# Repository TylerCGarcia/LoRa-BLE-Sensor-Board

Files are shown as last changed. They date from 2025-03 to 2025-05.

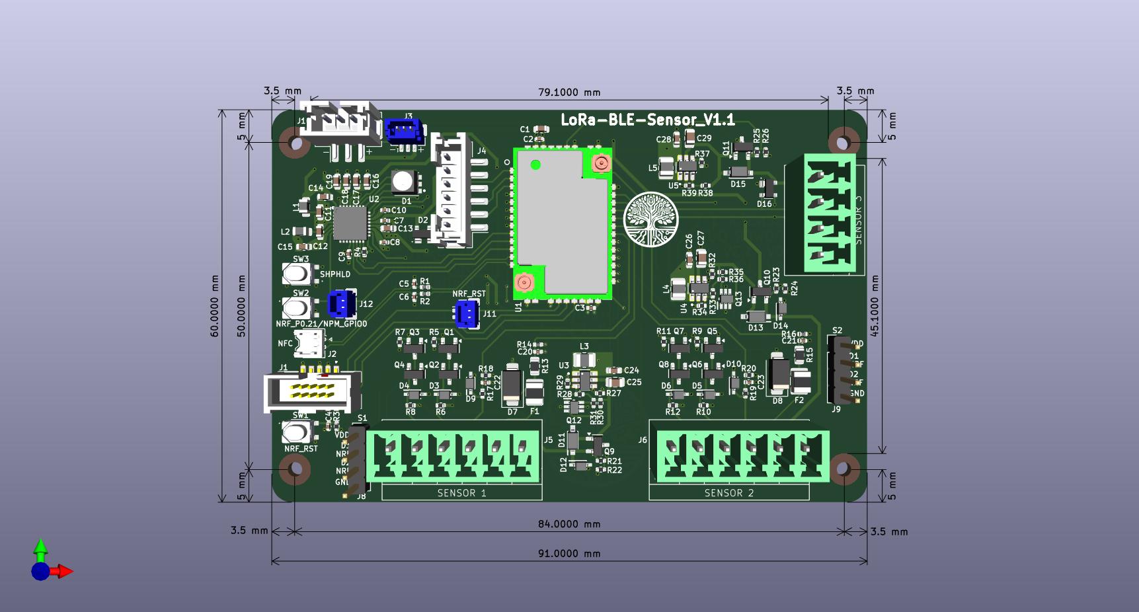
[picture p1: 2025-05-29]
docs/LoRa-BLE-Sensor_V1.1/LoRa-BLE-Sensor_V1.1.jpg

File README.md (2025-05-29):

# LoRa_BLE_Sensor Board
CAD: KiCad 9.0
# Overview
A RAK4630 based sensor board that uses BLE and LoRaWAN. This board is configured to use three industrial sensors simultaneously. 

Sensor 1 and Sensor 2 are designed so the sensor can be powered with 3.3V, 5V, 12V or 24V that are switched between through firmware. Sensor 3 has the options for 3.3V or 5V. It is designed for each sensor to have its own unique 
power supply, independent of the other sensor. Sensor 1 and Sensor 2 are designed for work with either digital or analog sensors. Sensor 3 is deisned for digital sensors with 3.3V logic level or to control up to two relays.

# Schematic Breakdown
**RAK4630** 
 - A combination module of an nRF52840 and SX1262
   * The nRF52840 has a cortex M4 and uses BLE
   * The SX1262 is a SPI controlled LoRa chip
 - There is an SWD connector for programming
 - There are two buttons
   * SW1 is connected to the reset pin on the nRF52840
   * SW2 is connected to P0.09

**NPM1300** 
 - Power management for the board
   * Programmable over I2C with the RAK4630
 - Used to charge the battery and works as a fuel guage
 - Contains two buck converters
   * Buck 1 is used for Sensor 3 3.3V output
   * Buck 2 is used at 3.3V to supply Vdd for the entire board
 - Contains 2 LDOs
   * Used if either Sensor 1 or Sensor 2 are set to 3.3V
 - Switch SW3
   * Used to change power modes on npm1300 or to do a power cycle of the board
 - RGB LED
   * Used for charging/error status of the npm1300 and as an led controlled by RAK4630

**Boost 1** 
 - TLV61046ADBVR Boost Converter
   * Up to 28V output with load disconnect
   * Output is determined by resistors in feedback
 - NMOS mosfets
   * Allow for feedback reistances to be changes to adjust output
   * BOOST1_FB_CTRL1 set to 0, BOOST1_FB_CTRL2 set to 0 --> 24V
   * BOOST1_FB_CTRL1 set to 1, BOOST1_FB_CTRL2 set to 0 --> 12V
   * BOOST1_FB_CTRL1 set to 0, BOOST1_FB_CTRL2 set to 1 --> 6V
   * BOOST1_FB_CTRL1 set to 1, BOOST1_FB_CTRL2 set to 1 --> 5V

**Boost 2** 
 - TLV61046ADBVR Boost Converter
   * Up to 28V output with load disconnect
   * Output is determined by resistors in feedback
 - NMOS mosfets
   * Allow for feedback reistances to be changes to adjust output
   * BOOST2_FB_CTRL1 set to 0, BOOST2_FB_CTRL2 set to 0 --> 24V
   * BOOST2_FB_CTRL1 set to 1, BOOST2_FB_CTRL2 set to 0 --> 12V
   * BOOST2_FB_CTRL1 set to 0, BOOST2_FB_CTRL2 set to 1 --> 6V
   * BOOST2_FB_CTRL1 set to 1, BOOST2_FB_CTRL2 set to 1 --> 5V

**Boost 3** 
 - TLV61046ADBVR Boost Converter
   * Up to 28V output with load disconnect
   * Output is determined by resistors in feedback
 - This boost has one configuration which is 5V

**Sensor 3 ESD**
 - ESD protection for Sensor 3 power and digital lines
  * ESD is for 5V for power and 3.3V for input lines

**Power Switches** 
 - Connects boost and ldo/buck outputs so only 1 is used by the sensor
   * Boost outputs have priority if both are enabled
 - ESD protection for sensor power
   * Designed for 24V for Sensor 1 and Sensor 2
   
**Digital Inputs** 
 - MOSFET based level shifters
   * Allows sensor digital logic to be translated from sensor power to Vdd
 - ESD protection for digital inputs
   * Designed for 24V for Sensor 1 and Sensor 2

**Analog Inputs** 
 - 5 inputs meant for external sensors
   * 2 designed for 4-20mA current sensors
   * 2 designed to read voltages up to 28V
   * 3 designed for feedback to the voltage of the sensor power

**USB** 
 - 6 pin jst PH connector to use with external USB-C connector
 - ESD protection for data lines and USB power

**Interface** 
 - Three screw terminal connectors for the sensors
   * Designed for pluggaple screw terminals
 
**Debug**
 - Two JST SH connectors for interfacing with Button 1 and nRF Reset
 - Two 2.54mm pin header for debugging Sensor 1 and Sensor 2

# Power Analysis

# Bugs/To-Do
- Add fuses to sensor power outputs

# Revision History
Current Version: **V1.1**

Version Breakdown: `[Major Chanegs]`.`[Minor Changes]`

### V1.1
- Changed level shifters for sensor to have isolation from output
- Removed 18650 battery connectors and NTC
  * Replaced with 3 pin JST PH and JST SH for external battery
- Removed on board relay
- Added Sensor 3 connectors
 * Can be configured for digital sensors with 3.3V or 5V output
 * Output is either 5V from boost converter or Buck 1 of npm1300
 * This connector can be used for an external relay
- Added 2 pin JST SH connectors to have Button 1 and nRF Reset pins be external if desired
- Added connector for NFC antenna
- Changed mounting holes from M3 to M2

### V1.0
- Initial Design of Board

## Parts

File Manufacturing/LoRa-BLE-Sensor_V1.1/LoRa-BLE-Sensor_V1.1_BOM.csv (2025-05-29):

Item # | Ref Des | Qty | Manufacturer | Mfg Part # | Description/Value | Package | Type | Price per Part for 10 | Price per Board | Price per Part for 100 | Price per Board | Distributor
1 | U1 | 1 | RAK Wireless | RAK4630 | BLE/LoRa Wireless Module nRF52840 and SX1262 | 24-TFQFN | SMD | $15.00 | $15.00 | $15.00 | $15.00 | RAK
2 | U2 | 1 | Nordic Semiconductor | nPM1300-QEAA-R | Battery Management POWER MANAGEMENT IC | GFN32 | SMD | $1.68 | $1.68 | $1.50 | $1.50 | Digikey
3 | U3, U4, U5 | 3 | Texas Instruments | TLV61046ADBVR | BOOST CONVERTER 28V OUTPUT ADJUSTABLE | SOT-23-6 | SMD | $0.79 | $2.37 | $0.71 | $2.14 | Mouser
4 | Q1, Q2, Q3, Q4, Q5, Q6, Q7, Q8 | 8 | Diodes Incorporated | DMN67D7L-7 | N-CHANNEL 1 CHANNEL 40VGS 60VDS 800mVGSth 1.5Ohms | SOT-23-3 | SMD | $0.13 | $1.06 | $0.08 | $0.66 | Mouser
5 | Q9, Q10, Q11 | 3 | Vishay | SQ2389ES-T1_GE3 | P-CHANNEL 1 CHANNEL 20VGS 40VDS 1.5VGSth 94mOhms | SOT-23-3 | SMD | $0.50 | $1.50 | $0.38 | $1.15 | Mouser
6 | Q12, Q13 | 2 | Diodes Incorporated | DMN62D0UDW-7 | N-CHANNEL 2 CHANNEL 20VGS 60VDS 500mVGSth 2Ohms | SOT-363-6 | SMD | $0.13 | $0.27 | $0.09 | $0.18 | Mouser
7 | D1 | 1 | Broadcom | ASMB-TTF0-0A20B | RGB LED 20mA 2.1V, 2.9V, 2.9V | PLCC-6 | SMD | $0.31 | $0.31 | $0.18 | $0.18 | Mouser
8 | D2, D16 | 2 | Nexperia | PRTR5V0U2X,215 | ESD Bidirectional DIODE 2 CHANNEL 5V Working 6V BREAKDOWN 1pF | SOT-143B-4 | SMD | $0.33 | $0.66 | $0.23 | $0.46 | Mouser
9 | D3, D4, D5, D6, D9, D10, D12, D14 | 8 | YAGEO | UDD32C24L01 | ESD Bidirectional Diode 24V Working 56V Clamp 26.7V Breakdown 0.8pF | SOD-323 | SMD | $0.18 | $1.46 | $0.09 | $0.71 | Mouser
10 | D7, D8 | 2 | Littlefuse | SMAJ10CA | ESD Bidirectional Diode 17V Clamp 11.1V Breakdown 23.5A | DO-214AC | SMD | $0.26 | $0.52 | $0.21 | $0.42 | Mouser
11 | D11, D13, D15 | 3 | Vishay | BAT54W-HG3-08 | Schottky Diode 240mV 200mA | SOD-123-2 | SMD | $0.18 | $0.55 | $0.12 | $0.35 | Mouser
12 | L1, L2 | 2 | Murata | LQM21PH2R2MGCD | IND SHIELDED 2.2uH 800mA DC 290mOhms | 0805 | SMD | $0.19 | $0.38 | $0.15 | $0.30 | Mouser
13 | L3, L4, L5 | 3 | Murata | 1239AS-H-100M=P2 | IND SHIELDED 10UH 850mA DC 460mOhms | 1008 | SMD | $0.21 | $0.63 | $0.16 | $0.49 | Mouser
14 | F1, F2 | 2 | Bourns | MF-USMF005-2 | PTC Resettable Fuse 30V 150mA Trip 2.8Ohm Initial 50 Ohm Post Trip 50mA Hold | 1210 | SMD | $0.30 | $0.61 | $0.23 | $0.47 | Mouser
15 | C1, C11, C12, C13, C14, C15, C16, C17, C18, C19, C24, C26, C28 | 13 | Murata | GRM188Z71A106MA73J | CAP CER 10UF 10VDC 20% X7R | 0603 | SMD | $0.21 | $2.68 | $0.13 | $1.69 | Mouser
16 | C25, C27, C29 | 3 | Murata | GRM21BR61H106ME43L | CAP CER 10UF 50VDC 20% X5R | 0805 | SMD | $0.22 | $0.66 | $0.13 | $0.38 | Mouser
17 | C2, C3, C4, C9 | 4 | Murata | GRM155R71C104KA88J | CAP CER 100NF 16VDC 10% X7R | 0402 | SMD | $0.01 | $0.02 | $0.00 | $0.02 | Mouser
18 | C5, C6 | 2 |  |  | DNP | 0402 | DNP
19 | C7, C10 | 2 | Murata | GRM155Z71A105KE01D | CAP CER 1UF 10VDC 10% X7R | 0402 | SMD | $0.02 | $0.04 | $0.02 | $0.03 | Mouser
20 | C8 | 1 | Murata | GRM155Z71A225KE01D | CAP CER 2.2UF 10VDC 10% X7R | 0402 | SMD | $0.11 | $0.11 | $0.06 | $0.06 | Mouser
21 | C20, C21, C22, C23 | 4 | Murata | GRM1555C1H471JA01D | CAP CER 470pF 50V 5% C0G | 0402 | SMD | $0.03 | $0.12 | $0.02 | $0.07 | Mouser
22 | R1, R2 | 2 | Panasonic | ERJ-2GE0R00X | RES 0 OHM 1/10W 5% 0PPM/C | 0402 | SMD | $0.01 | $0.02 | $0.01 | $0.02 | Mouser
23 | R3, R5, R6, R7, R8, R9, R10, R11, R12, R27, R32, R37 | 12 | Panasonic | ERJ-2RKF1002X | RES 10K OHM 1/10W 1% 50V 100PPM/C | 0402 | SMD | $0.02 | $0.28 | $0.01 | $0.16 | Mouser
24 | R4 | 1 | Panasonic | ERJ-2RKF3003X | RES 300K OHM 1/10W 1% 50V 100PPM/C | 0402 | SMD | $0.02 | $0.02 | $0.01 | $0.01 | Mouser
25 | R13, R15 | 2 | Panasonic | ERJ-UP6F1800V | RES 180 OHM 1/2W 1% 400V 100PPM/C | 0805 | SMD | $0.09 | $0.17 | $0.06 | $0.12 | Mouser
26 | R14, R16 | 2 | Vishay | TNPW040250R0DEED | RES 50 OHM 130mW 0.5% 75V 25PPM/C | 0402 | SMD | $0.14 | $0.28 | $0.10 | $0.20 | Mouser
27 | R17, R19 | 2 | Panasonic | ERA-2AEB104X | RES 100K OHM 1/16W 0.1% 50V 25PPM/C | 0402 | SMD | $0.09 | $0.17 | $0.08 | $0.15 | Mouser
28 | R18, R20 | 2 | Panasonic | ERA-2AEB133X | RES 13K OHM 1/16W 0.1% 50V 25PPM/C | 0402 | SMD | $0.09 | $0.17 | $0.08 | $0.15 | Mouser
29 | R21, R23, R25 | 3 | YAGEO | RE0402DRE071ML | RES 1M OHM 1/16W 0.5% 50V 50PPM/C | 0402 | SMD | $0.03 | $0.08 | $0.02 | $0.06 | Mouser
30 | R22, R24, R26 | 3 | KOA Speer | RN73R1ETTP1303B25 | RES 130KOHM 1/10W 0.1% 50V 25PPM/C | 0402 | SMD | $0.07 | $0.20 | $0.06 | $0.19 | Mouser
31 | R28, R33 | 2 | Vishay | CRCW04022M10FKED | RES 2.1M OHM 1/16W 1% 50V 100PPM/C | 0402 | SMD | $0.02 | $0.03 | $0.01 | $0.03 | Mouser
32 | R29, R34, R39 | 3 | Vishay | CRCW040271K5FKED | RES 71.5K OHM 1/16W 1% 50V 100PPM/C | 0402 | SMD | $0.02 | $0.06 | $0.02 | $0.05 | Mouser
33 | R30, R35 | 2 | Vishay | CRCW04021M96FKED | RES 1.96M OHM 1/16W 1% 50V 100PPM/C | 0402 | SMD | $0.02 | $0.03 | $0.01 | $0.03 | Mouser
34 | R31, R36 | 2 | Vishay | CRCW0402604KFKED | RES 604K OHM 1/16W 1% 50V 100PPM/C | 0402 | SMD | $0.02 | $0.03 | $0.01 | $0.03 | Mouser
35 | R38 | 1 | Vishay | CRCW0402383KFKED | RES 383K OHM 1/16W 1% 50V 100PPM/C | 0402 | SMD | $0.03 | $0.03 | $0.02 | $0.02 | Mouser
36 | SW1, SW2, SW3 | 3 | C&K | PTS815SJM250SMTR LFS | Tactile Switch 12VDC 50mA 4.2mm x 3.2mm x 1.55mm |  | SMD | $0.19 | $0.58 | $0.16 | $0.47 | Mouser
37 | J1 | 1 | ANY | SHF-105-01-L-D-SM-TR | 10 PIN SHROUDED 2x5 DIRECTIONAL 1.27mm PITCH |  | SMD | $0.16 | $0.16 | $0.16 | $0.16 | AliExpress
38 | J2 | 1 | JST | BM02B-ACHSS-GAN-ETF | 2-PIN JST ACH 1.2mm |  | SMD | $0.44 | $0.44 | $0.37 | $0.37 | LCSC
39 | J3 | 1 | JST | BM03B-SRSS-TB | 3-PIN JST SH HEADER VERTICAL 1mm PITCH |  | SMD | $0.21 | $0.21 | $0.16 | $0.16 | LCSC
40 | J4 | 1 | JST | B6B-PH-SM4-TB(LF)(SN) | 6-PIN JST PH HEADER VERTICAL 2mm PITCH |  | SMD | $0.32 | $0.32 | $0.25 | $0.25 | LCSC
41 | J5, J6 | 2 | Pheonix Contact | 1803468 | 6 Input Screw Terminal 3.81 mm Pitch Plug Connector |  | Thru-Hole | $0.60 | $1.20 | $0.32 | $0.64 | AliExpress
42 | J7 | 1 | Pheonix Contact | 1803442 | 4 Input Screw Terminal 3.81 mm Pitch Plug Connector |  | Thru-Hole | $0.50 | $0.50 | $0.50 | $0.50 | AliExpress
43 | J8, J9 | 2 | ANY |  | 1x4 Pin Header 2.54mm Pitch |  | Thru-Hole | $0.10 | $0.20 | $0.10 | $0.20 | AliExpress
44 | J10 | 1 | JST | B3B-PH-SM4-TB | 3-PIN JST PH HEADER VERTICAL 2mm PITCH |  | SMD | $0.21 | $0.21 | $0.17 | $0.17 | LCSC
45 | J11, J12 | 2 | JST | BM02B-SRSS-TB | 2-PIN JST SH HEADER VERTICAL 1mm PITCH |  | SMD | $0.14 | $0.28 | $0.11 | $0.22 | LCSC
 | Total Components | 124 |  |  |  |  |  | Total Price | $36.28 | Total Price | $30.59

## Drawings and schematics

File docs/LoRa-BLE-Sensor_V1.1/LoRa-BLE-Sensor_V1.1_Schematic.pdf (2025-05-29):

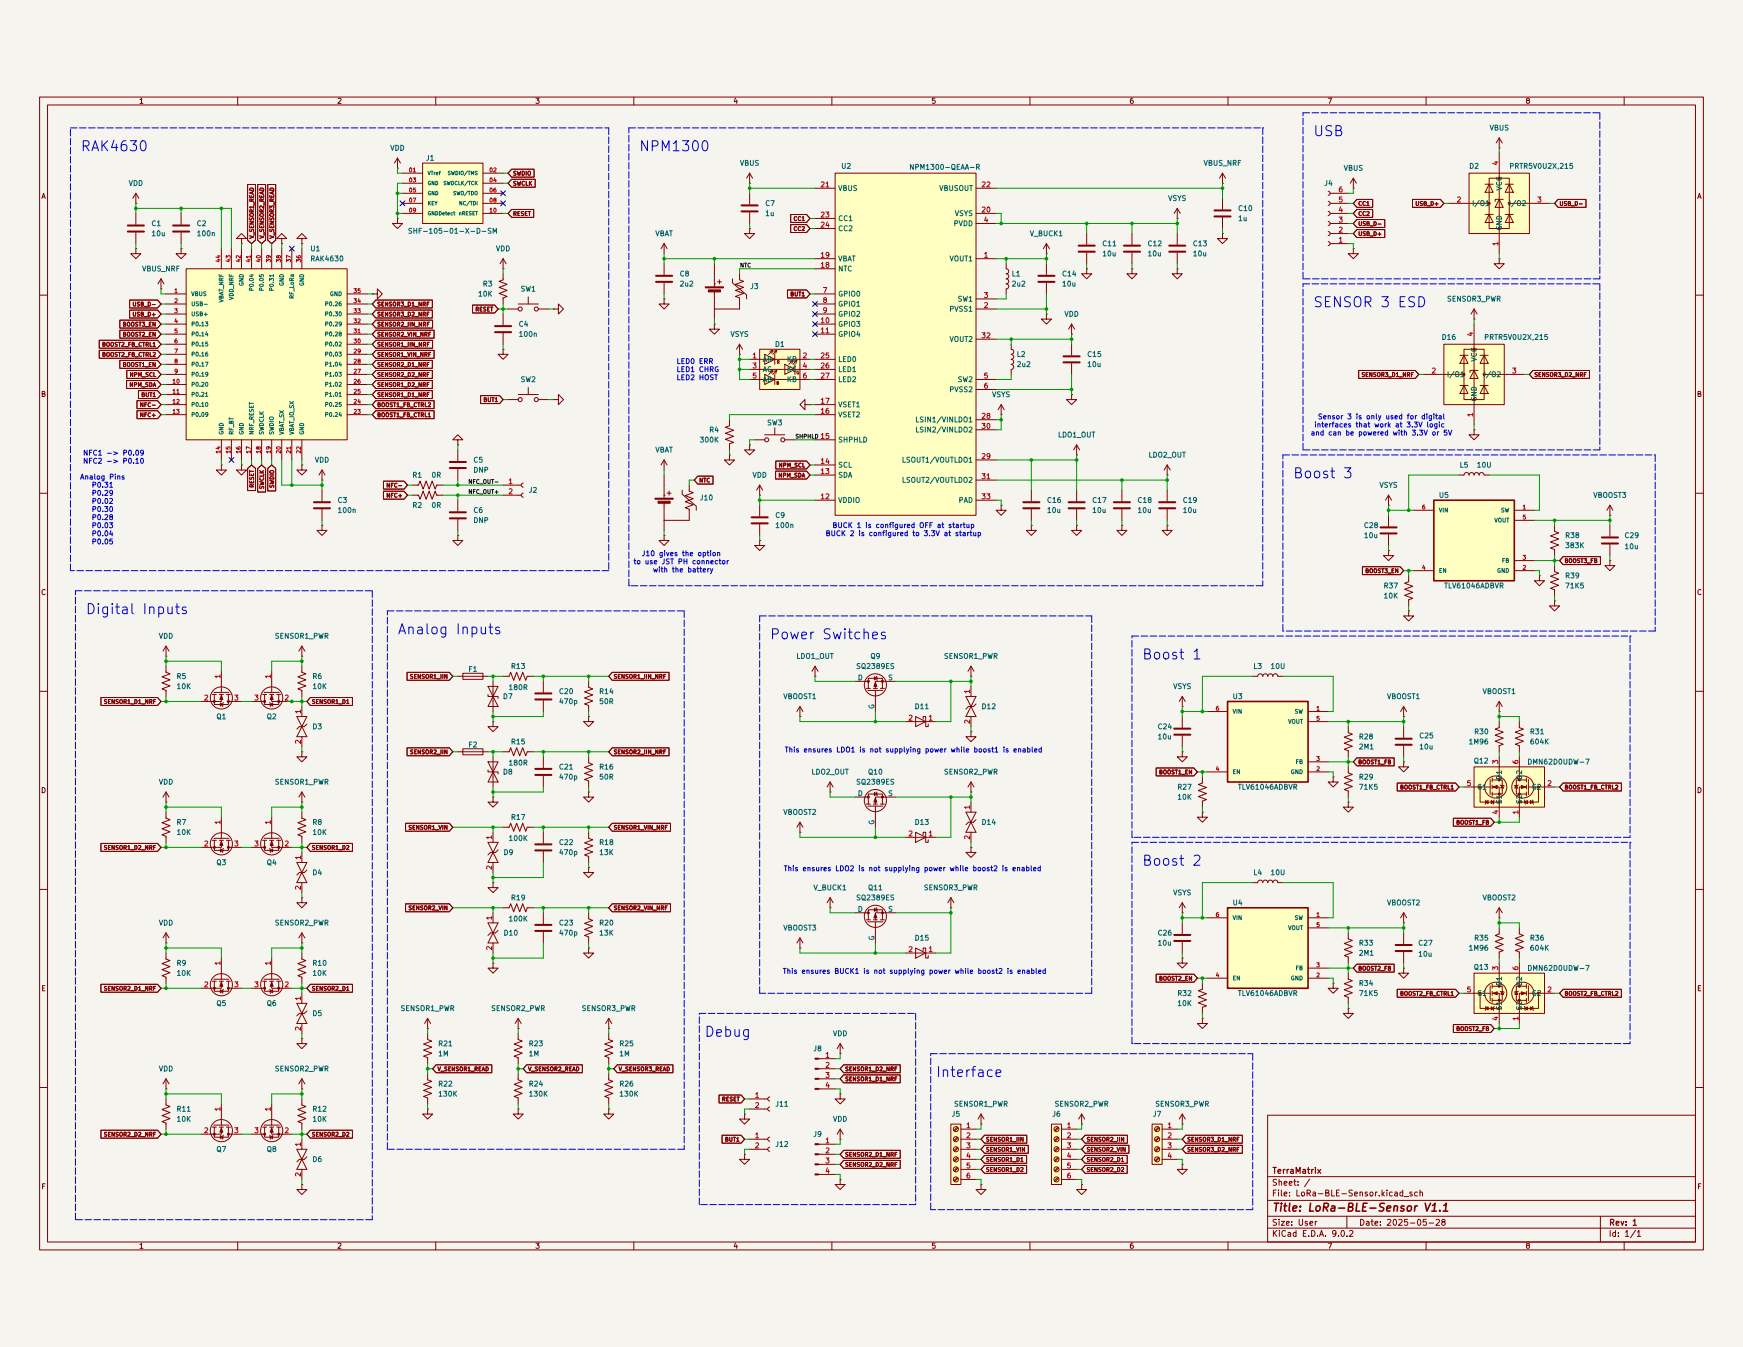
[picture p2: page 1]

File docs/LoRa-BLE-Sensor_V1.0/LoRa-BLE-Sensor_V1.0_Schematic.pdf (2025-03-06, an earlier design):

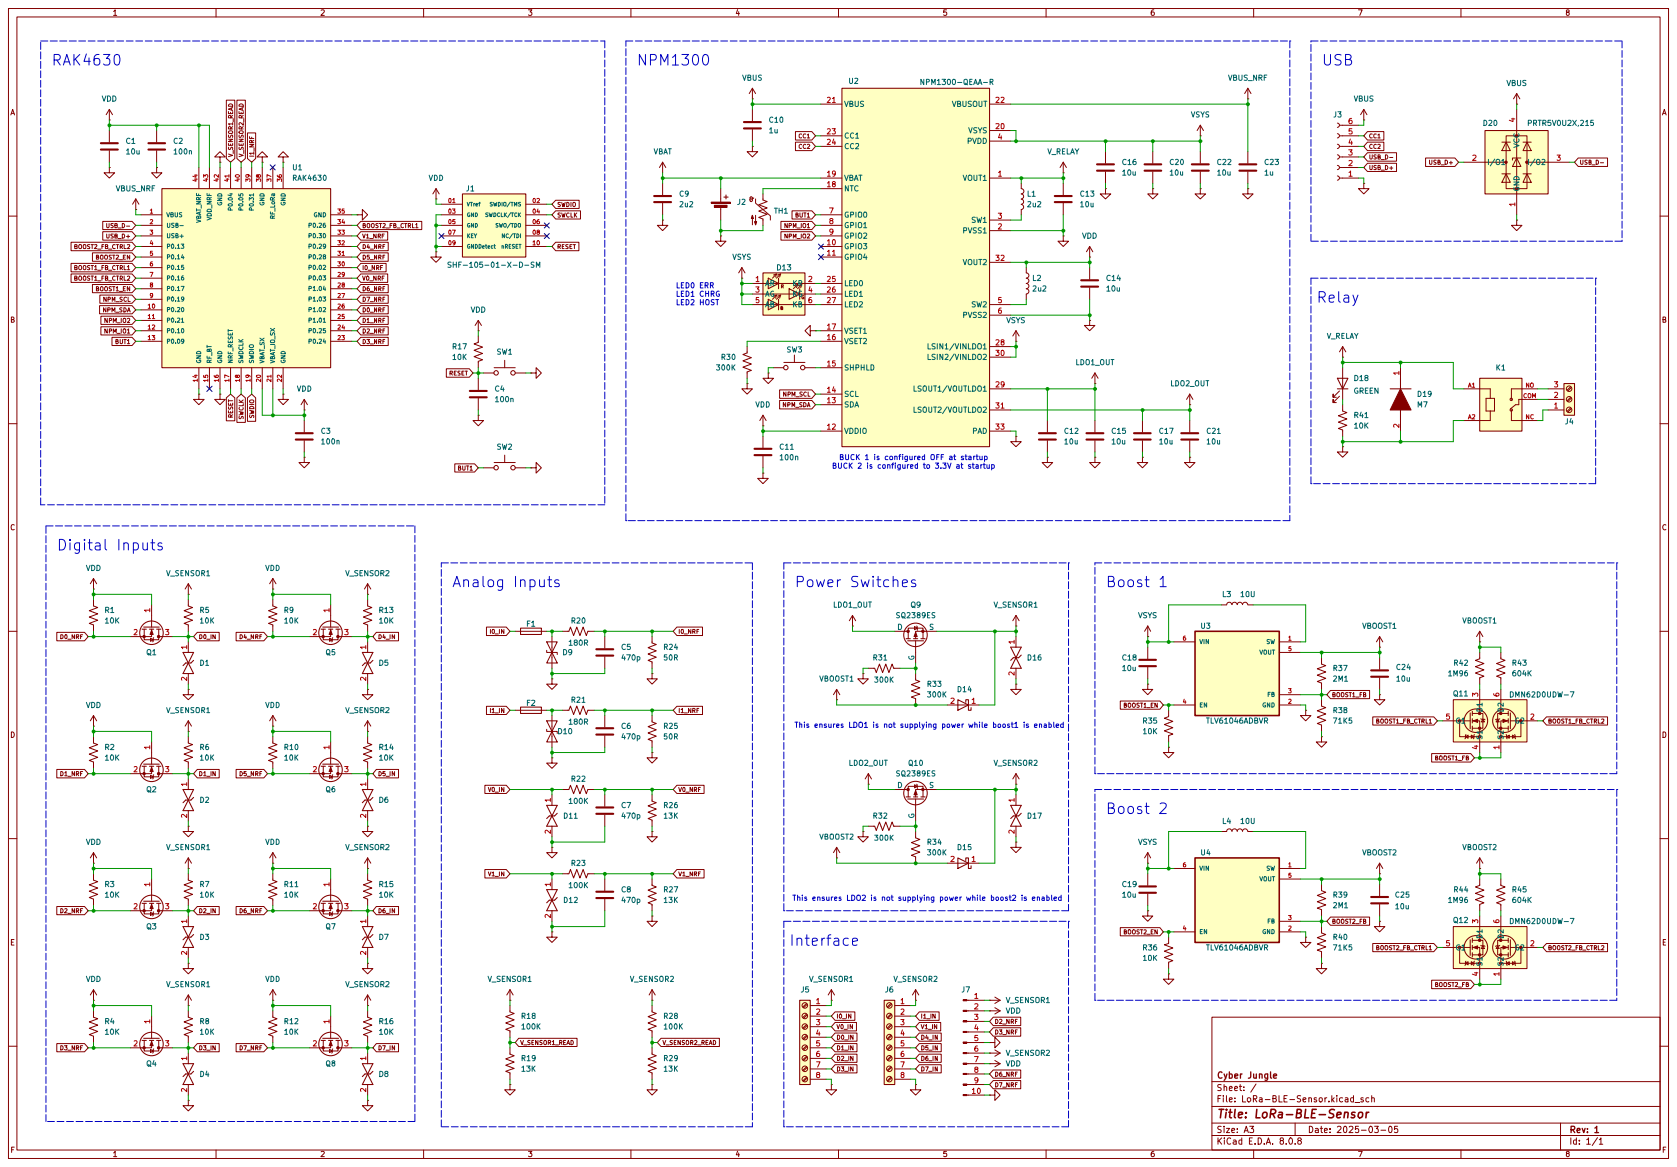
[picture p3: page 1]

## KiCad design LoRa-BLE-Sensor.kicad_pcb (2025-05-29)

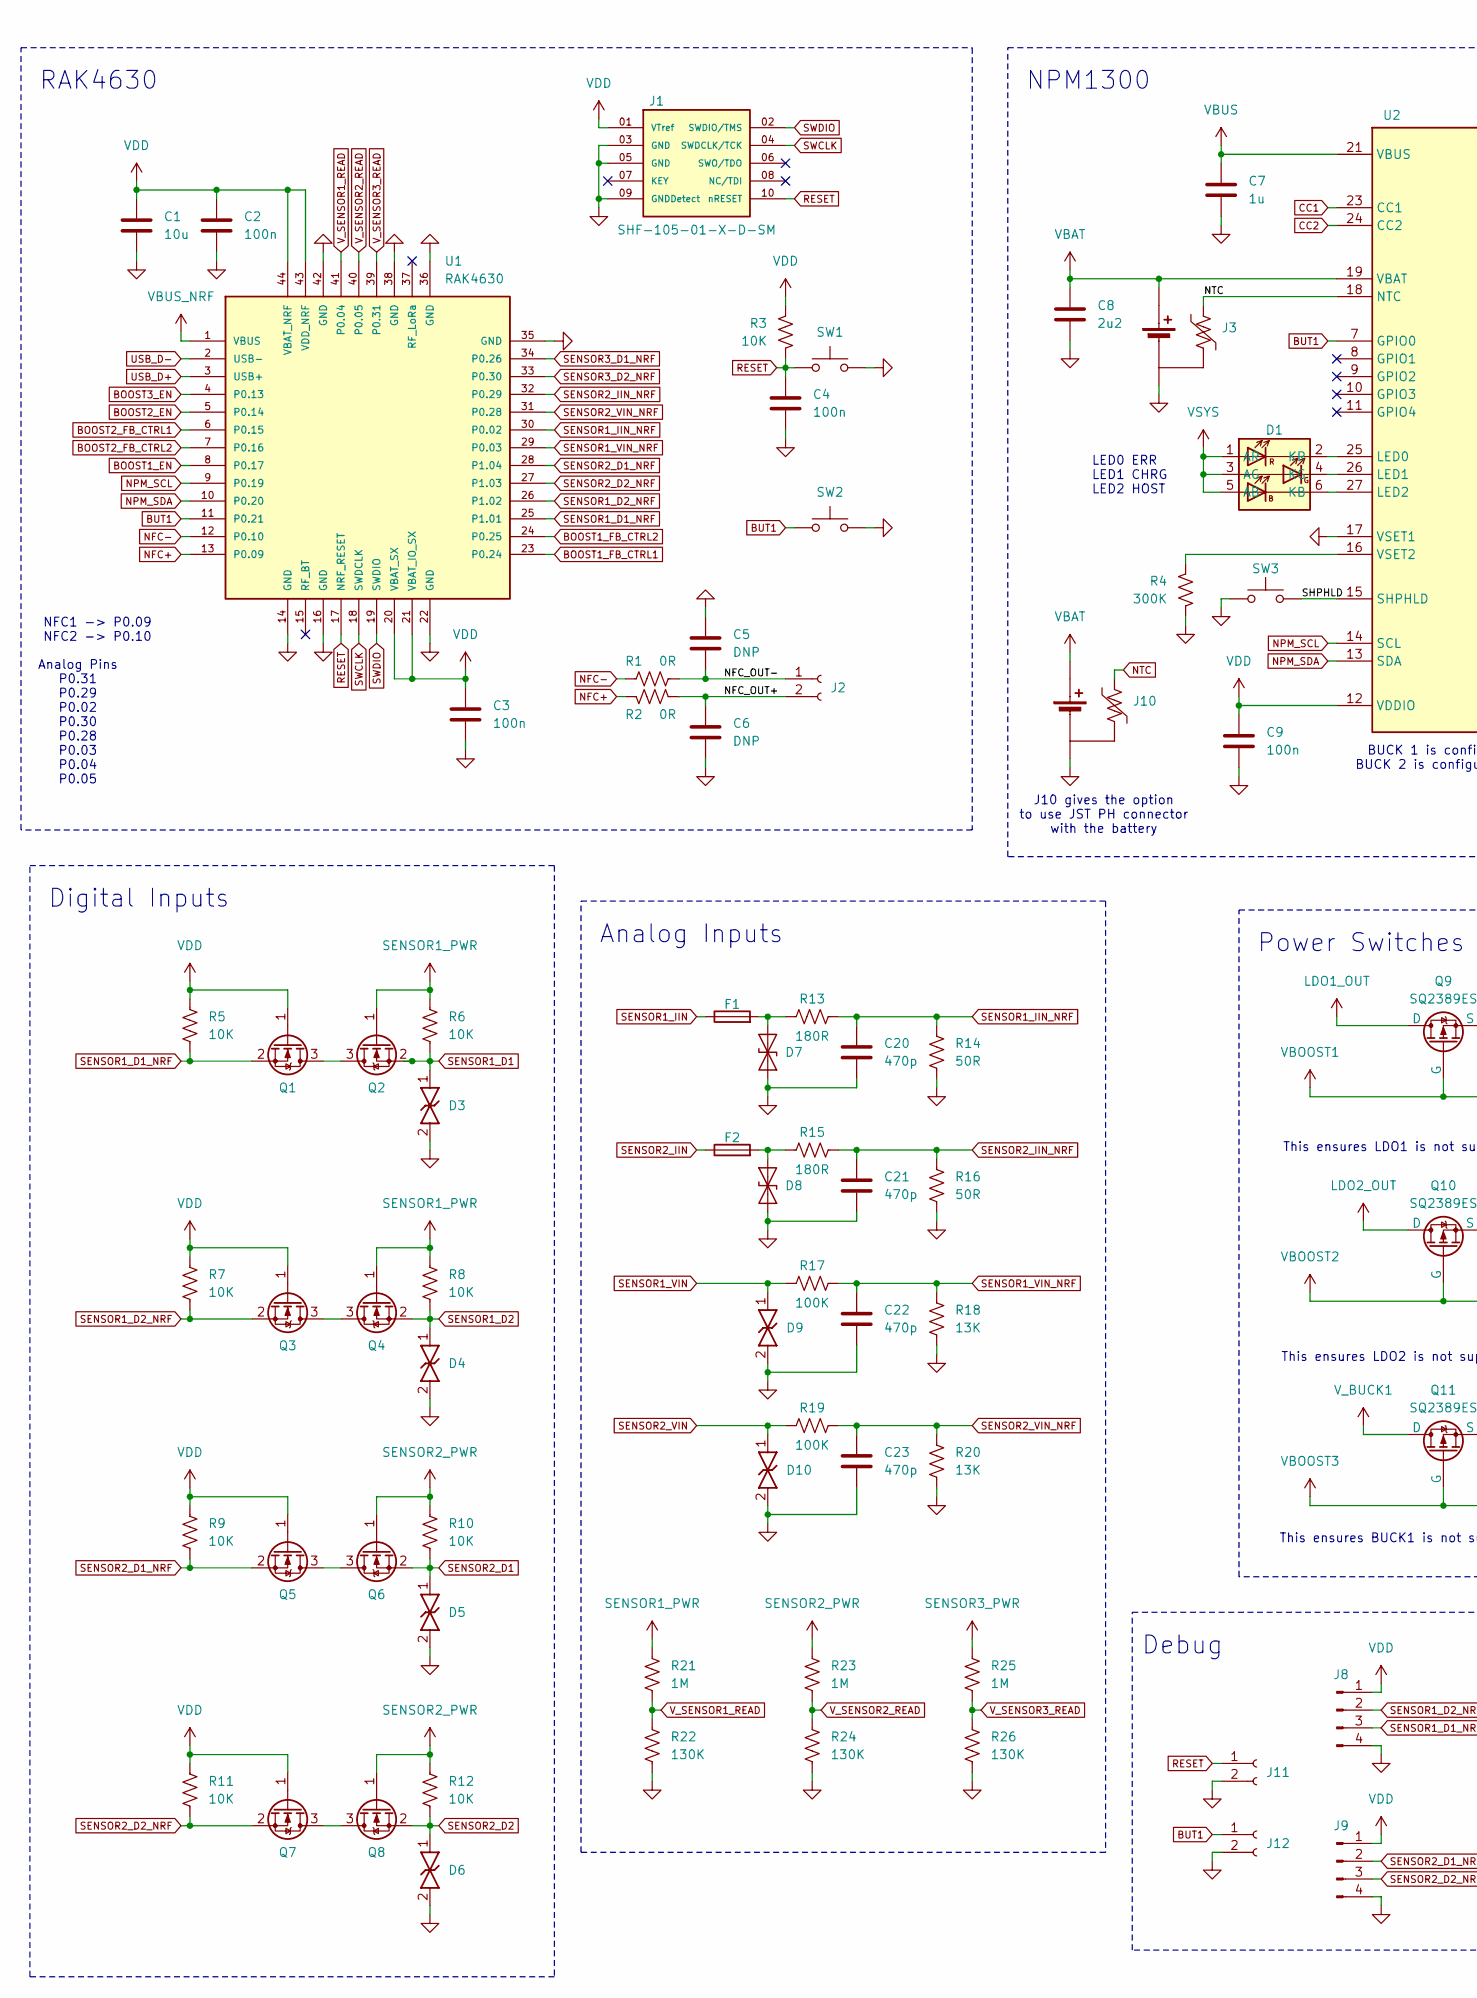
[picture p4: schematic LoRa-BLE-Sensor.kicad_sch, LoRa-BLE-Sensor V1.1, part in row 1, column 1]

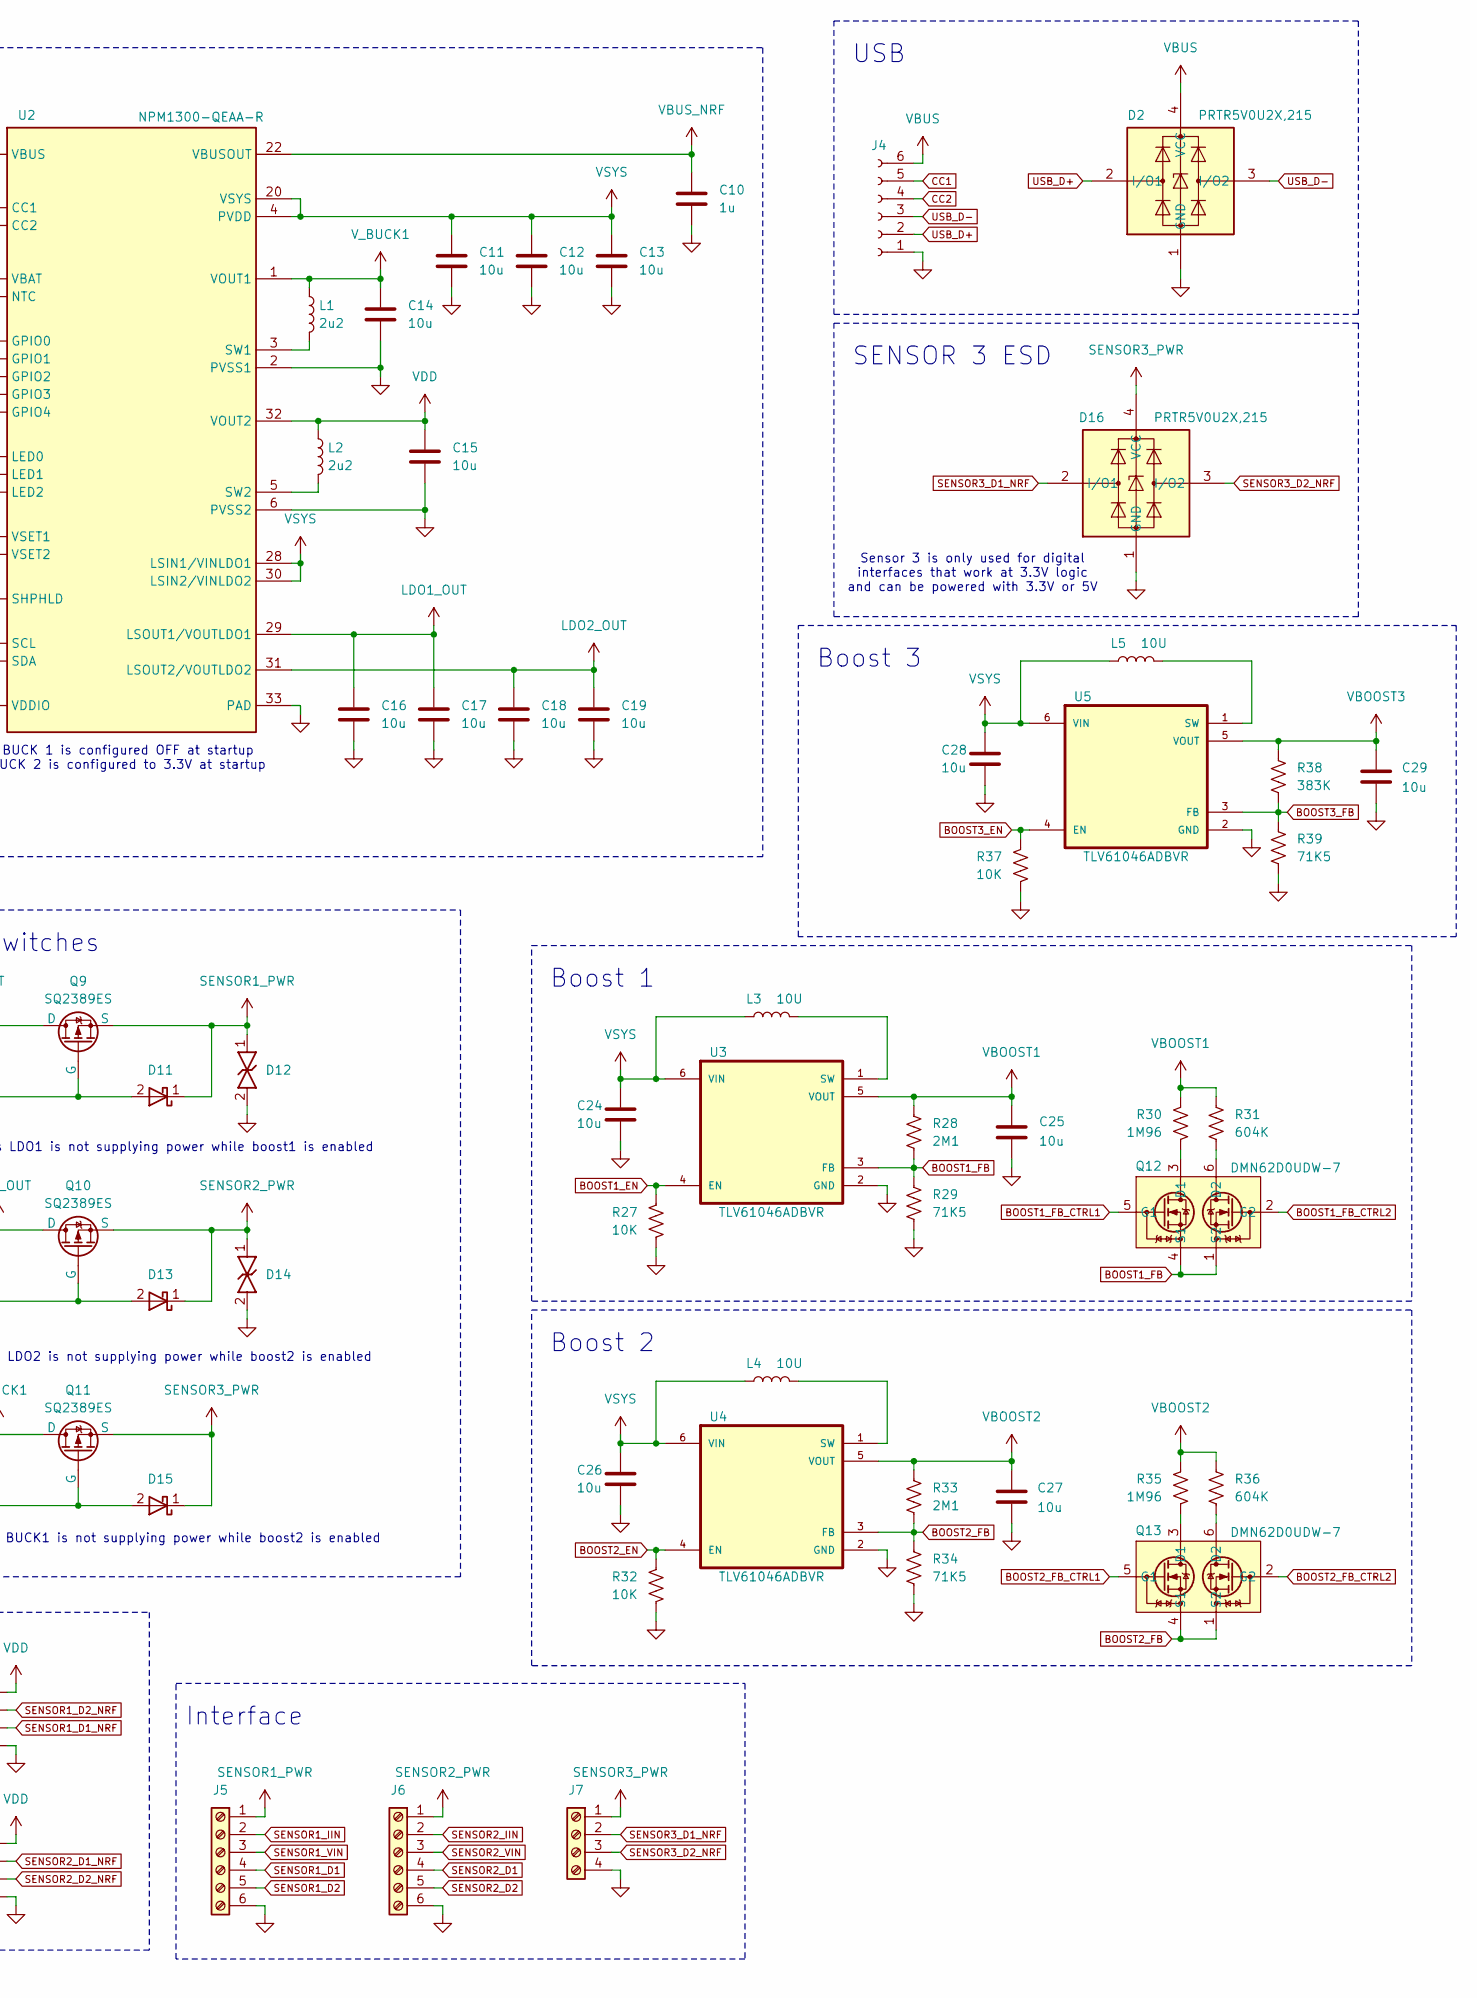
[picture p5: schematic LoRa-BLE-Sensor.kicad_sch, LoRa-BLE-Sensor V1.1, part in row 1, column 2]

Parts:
C1, C11, C12, C13, C14, C15, C16, C17, C18, C19, C24, C26, C28: 10u; C_0603_1608Metric
C2, C3, C4, C9: 100n; C_0402_1005Metric
C5, C6: DNP; C_0402_1005Metric
C7, C10: 1u; C_0402_1005Metric
C8: 2u2; C_0402_1005Metric
C20, C21, C22, C23: 470p; C_0402_1005Metric
C25, C27, C29: 10u; C_0805_2012Metric
D1: ASMB-TTF0-0A20B; ASMBTTF00A20B; Mouser Part Number 630-ASMB-TTF0-0A20B
D2, D16: PRTR5V0U2X,215; PRTR5V0U2X
D3, D4, D5, D6, D9, D10, D12, D14: UDD32C24L01; SOD2612X120N
D7, D8: SMAJ10CA; D_SMA
D11, D13, D15: BAT54W-HG3-08; SOD3716X135N
F1, F2: MF-USMF005-2; Fuse_1210_3225Metric
J1: SHF-105-01-X-D-SM; SAMTEC_SHF-105-01-X-D-SM
J2: Conn_01x02_Socket; JST_ACH_BM02B-ACHSS-GAN-ETF_1x02-1MP_P1.20mm_Vertical
J3: Battery_with_NTC; JST_SH_BM03B-SRSS-TB_1x03-1MP_P1.00mm_Vertical
J4: Conn_01x06_Socket; JST_6PIN_PH_VERTICAL_SMD
J5, J6: Screw_Terminal_01x06; PhoenixContact_MCV_1,5_6-G-3.81_1x06_P3.81mm_Vertical
J7: Screw_Terminal_01x04; PhoenixContact_MCV_1,5_4-G-3.81_1x04_P3.81mm_Vertical
J8, J9: Conn_01x04_Pin; PinHeader_1x04_P2.54mm_Vertical
J10: Battery_with_NTC; JST_3PIN_PH_Vertical
J11, J12: Conn_01x02_Socket; JST_SH_2-PIN_Vertical
L1, L2: 2u2; L_0805_2012Metric
L3, L4, L5: 10U; L_1008_2520Metric
Q1, Q2, Q3, Q4, Q5, Q6, Q7, Q8: DMN67D7L; SOT-23
Q9, Q10, Q11: SQ2389ES; SOT-23-3
Q12, Q13: DMN62D0UDW-7; SOT65P222X110-6N; Mouser Part Number 621-DMN62D0UDW-7
R1, R2: 0R; L_0402_1005Metric
R3, R5, R6, R7, R8, R9, R10, R11, R12, R27, R32, R37: 10K; R_0402_1005Metric
R4: 300K; R_0402_1005Metric
R13, R15: 180R; R_0805_2012Metric
R14, R16: 50R; L_0402_1005Metric
R17, R19: 100K; R_0402_1005Metric
R18, R20: 13K; R_0402_1005Metric
R21, R23, R25: 1M; R_0402_1005Metric
R22, R24, R26: 130K; R_0402_1005Metric
R28, R33: 2M1; R_0402_1005Metric
R29, R34, R39: 71K5; R_0402_1005Metric
R30, R35: 1M96; R_0402_1005Metric
R31, R36: 604K; R_0402_1005Metric
R38: 383K; R_0402_1005Metric
SW1, SW2, SW3: SW_Push; PTS815SJM250SMTRLFS_2Pin
U1: RAK4630
U2: NPM1300-QEAA-R; QFN50P500X500X90-33N
U3, U4, U5: TLV61046ADBVR; SOT95P280X145-6N

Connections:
/NFC_OUT+: C6.1, J2.2, R2.2
/NFC_OUT-: C5.1, J2.1, R1.2
/SHPHLD: SW3.2, U2.15 (SHPHLD)
BOOST1_EN: R27.1, U1.8 (P0.17), U3.4 (EN)
BOOST1_FB: Q12.1 (S2), Q12.4 (S1), R28.2, R29.1, U3.3 (FB)
BOOST1_FB_CTRL1: Q12.5 (G1), U1.23 (P0.24)
BOOST1_FB_CTRL2: Q12.2 (G2), U1.24 (P0.25)
BOOST2_EN: R32.1, U1.5 (P0.14), U4.4 (EN)
BOOST2_FB: Q13.1 (S2), Q13.4 (S1), R33.2, R34.1, U4.3 (FB)
BOOST2_FB_CTRL1: Q13.5 (G1), U1.6 (P0.15)
BOOST2_FB_CTRL2: Q13.2 (G2), U1.7 (P0.16)
BOOST3_EN: R37.1, U1.4 (P0.13), U5.4 (EN)
BOOST3_FB: R38.2, R39.1, U5.3 (FB)
BUT1: J12.1, SW2.1, U1.11 (P0.21), U2.7 (GPIO0)
CC1: J4.5, U2.23 (CC1)
CC2: J4.4, U2.24 (CC2)
GND: C1.2, C2.2, C3.2, C4.2, C5.2, C6.2, C7.2, C8.2, C9.2, C10.2, C11.2, C12.2, C13.2, C14.2, C15.2, C16.2, C17.2, C18.2, C19.2, C20.2, C21.2, C22.2, C23.2, C24.2, C25.2, C26.2, C27.2, C28.2, C29.2, D2.1 (GND), D3.2, D4.2, D5.2, D6.2, D7.2 (A2), D8.2 (A2), D9.2, D10.2, D12.2, D14.2, D16.1 (GND), J1.03 (GND), J1.05 (GND), J1.09 (GNDDetect), J3.1 (-), J4.1, J5.6, J6.6, J7.4, J8.4, J9.4, J10.1 (-), J11.2, J12.2, R4.2, R14.2, R16.2, R18.2, R20.2, R22.2, R24.2, R26.2, R27.2, R29.2, R32.2, R34.2, R37.2, R39.2, SW1.2, SW2.2, SW3.1, U1.14 (GND), U1.16 (GND), U1.22 (GND), U1.35 (GND), U1.36 (GND), U1.38 (GND), U1.42 (GND), U2.2 (PVSS1), U2.6 (PVSS2), U2.17 (VSET1), U2.33 (PAD), U3.2 (GND), U4.2 (GND), U5.2 (GND)
LDO1_OUT: C16.1, C17.1, Q9.3 (D), U2.29 (LSOUT1/VOUTLDO1)
LDO2_OUT: C18.1, C19.1, Q10.3 (D), U2.31 (LSOUT2/VOUTLDO2)
NFC+: R2.1, U1.13 (P0.09)
NFC-: R1.1, U1.12 (P0.10)
NPM_SCL: U1.9 (P0.19), U2.14 (SCL)
NPM_SDA: U1.10 (P0.20), U2.13 (SDA)
NTC: J3.2 (NTC), J10.2 (NTC), U2.18 (NTC)
unnamed: D1.6 (KB), U2.27 (LED2)
unnamed: D1.4 (KG), U2.26 (LED1)
unnamed: D1.2 (KR), U2.25 (LED0)
unnamed: D7.1 (A1), F1.2, R13.1
unnamed: D8.1 (A1), F2.2, R15.1
unnamed: Q1.3 (D), Q2.3 (D)
unnamed: Q3.3 (D), Q4.3 (D)
unnamed: Q5.3 (D), Q6.3 (D)
unnamed: Q7.3 (D), Q8.3 (D)
unnamed: Q12.3 (D1), R30.2
unnamed: Q12.6 (D2), R31.2
unnamed: Q13.3 (D1), R35.2
unnamed: Q13.6 (D2), R36.2
unnamed: L1.2, U2.3 (SW1)
unnamed: L2.2, U2.5 (SW2)
unnamed: R4.1, U2.16 (VSET2)
unnamed: L3.2, U3.1 (SW)
unnamed: L4.2, U4.1 (SW)
unnamed: L5.2, U5.1 (SW)
RESET: C4.1, J1.10 (nRESET), J11.1, R3.2, SW1.1, U1.17 (NRF_RESET)
SENSOR1_D1: D3.1, J5.4, Q2.2 (S), R6.2
SENSOR1_D1_NRF: J8.3, Q1.2 (S), R5.2, U1.25 (P1.01)
SENSOR1_D2: D4.1, J5.5, Q4.2 (S), R8.2
SENSOR1_D2_NRF: J8.2, Q3.2 (S), R7.2, U1.26 (P1.02)
SENSOR1_IIN: F1.1, J5.2
SENSOR1_IIN_NRF: C20.1, R13.2, R14.1, U1.30 (P0.02)
SENSOR1_PWR: D11.1 (K), D12.1, J5.1, Q2.1 (G), Q4.1 (G), Q9.2 (S), R6.1, R8.1, R21.1
SENSOR1_VIN: D9.1, J5.3, R17.1
SENSOR1_VIN_NRF: C22.1, R17.2, R18.1, U1.29 (P0.03)
SENSOR2_D1: D5.1, J6.4, Q6.2 (S), R10.2
SENSOR2_D1_NRF: J9.2, Q5.2 (S), R9.2, U1.28 (P1.04)
SENSOR2_D2: D6.1, J6.5, Q8.2 (S), R12.2
SENSOR2_D2_NRF: J9.3, Q7.2 (S), R11.2, U1.27 (P1.03)
SENSOR2_IIN: F2.1, J6.2
SENSOR2_IIN_NRF: C21.1, R15.2, R16.1, U1.32 (P0.29)
SENSOR2_PWR: D13.1 (K), D14.1, J6.1, Q6.1 (G), Q8.1 (G), Q10.2 (S), R10.1, R12.1, R23.1
SENSOR2_VIN: D10.1, J6.3, R19.1
SENSOR2_VIN_NRF: C23.1, R19.2, R20.1, U1.31 (P0.28)
SENSOR3_D1_NRF: D16.2 (I/O1), J7.2, U1.34 (P0.26)
SENSOR3_D2_NRF: D16.3 (I/O2), J7.3, U1.33 (P0.30)
SENSOR3_PWR: D15.1 (K), D16.4 (VCC), J7.1, Q11.2 (S), R25.1
SWCLK: J1.04 (SWDCLK/TCK), U1.18 (SWDCLK)
SWDIO: J1.02 (SWDIO/TMS), U1.19 (SWDIO)
USB_D+: D2.2 (I/O1), J4.2, U1.3 (USB+)
USB_D-: D2.3 (I/O2), J4.3, U1.2 (USB-)
VBAT: C8.1, J3.3 (+), J10.3 (+), U2.19 (VBAT)
VBOOST1: C25.1, D11.2 (A), Q9.1 (G), R28.1, R30.1, R31.1, U3.5 (VOUT)
VBOOST2: C27.1, D13.2 (A), Q10.1 (G), R33.1, R35.1, R36.1, U4.5 (VOUT)
VBOOST3: C29.1, D15.2 (A), Q11.1 (G), R38.1, U5.5 (VOUT)
VBUS: C7.1, D2.4 (VCC), J4.6, U2.21 (VBUS)
VBUS_NRF: C10.1, U1.1 (VBUS), U2.22 (VBUSOUT)
VDD: C1.1, C2.1, C3.1, C9.1, C15.1, J1.01 (VTref), J8.1, J9.1, L2.1, Q1.1 (G), Q3.1 (G), Q5.1 (G), Q7.1 (G), R3.1, R5.1, R7.1, R9.1, R11.1, U1.20 (VBAT_SX), U1.21 (VBAT_IO_SX), U1.43 (VDD_NRF), U1.44 (VBAT_NRF), U2.12 (VDDIO), U2.32 (VOUT2)
VSYS: C11.1, C12.1, C13.1, C24.1, C26.1, C28.1, D1.1 (AR), D1.3 (AG), D1.5 (AB), L3.1, L4.1, L5.1, U2.4 (PVDD), U2.20 (VSYS), U2.28 (LSIN1/VINLDO1), U2.30 (LSIN2/VINLDO2), U3.6 (VIN), U4.6 (VIN), U5.6 (VIN)
V_BUCK1: C14.1, L1.1, Q11.3 (D), U2.1 (VOUT1)
V_SENSOR1_READ: R21.2, R22.1, U1.41 (P0.04)
V_SENSOR2_READ: R23.2, R24.1, U1.40 (P0.05)
V_SENSOR3_READ: R25.2, R26.1, U1.39 (P0.31)

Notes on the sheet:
Analog Pins P0.31 P0.29 P0.02 P0.30 P0.28 P0.03 P0.04 P0.05
Sensor 3 is only used for digital interfaces that work at 3.3V logic and can be powered with 3.3V or 5V
BUCK 1 is configured OFF at startup BUCK 2 is configured to 3.3V at startup
NPM1300
Boost 1
Debug
LED0 ERR LED1 CHRG LED2 HOST
RAK4630
This ensures LDO1 is not supplying power while boost1 is enabled
NFC1 -> P0.09 NFC2 -> P0.10
This ensures BUCK1 is not supplying power while boost2 is enabled
Digital Inputs
This ensures LDO2 is not supplying power while boost2 is enabled
J10 gives the option to use JST PH connector with the battery
USB
Boost 3
Power Switches
Interface
Analog Inputs
SENSOR 3 ESD
Boost 2

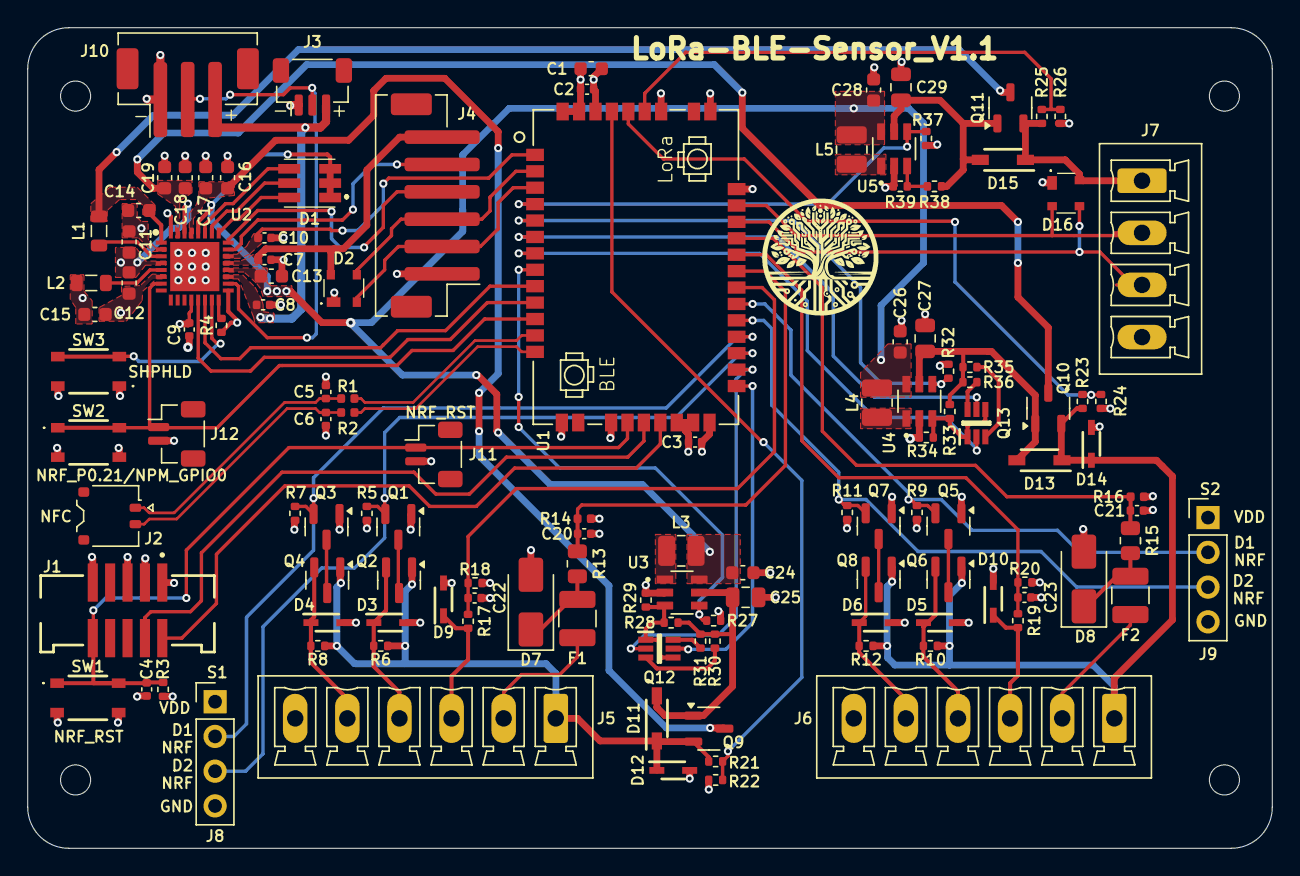
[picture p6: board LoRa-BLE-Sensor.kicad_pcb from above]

Board: 4 copper layers, 91.0 x 60.0 mm, 124 parts (0 on the bottom side), 81 nets.

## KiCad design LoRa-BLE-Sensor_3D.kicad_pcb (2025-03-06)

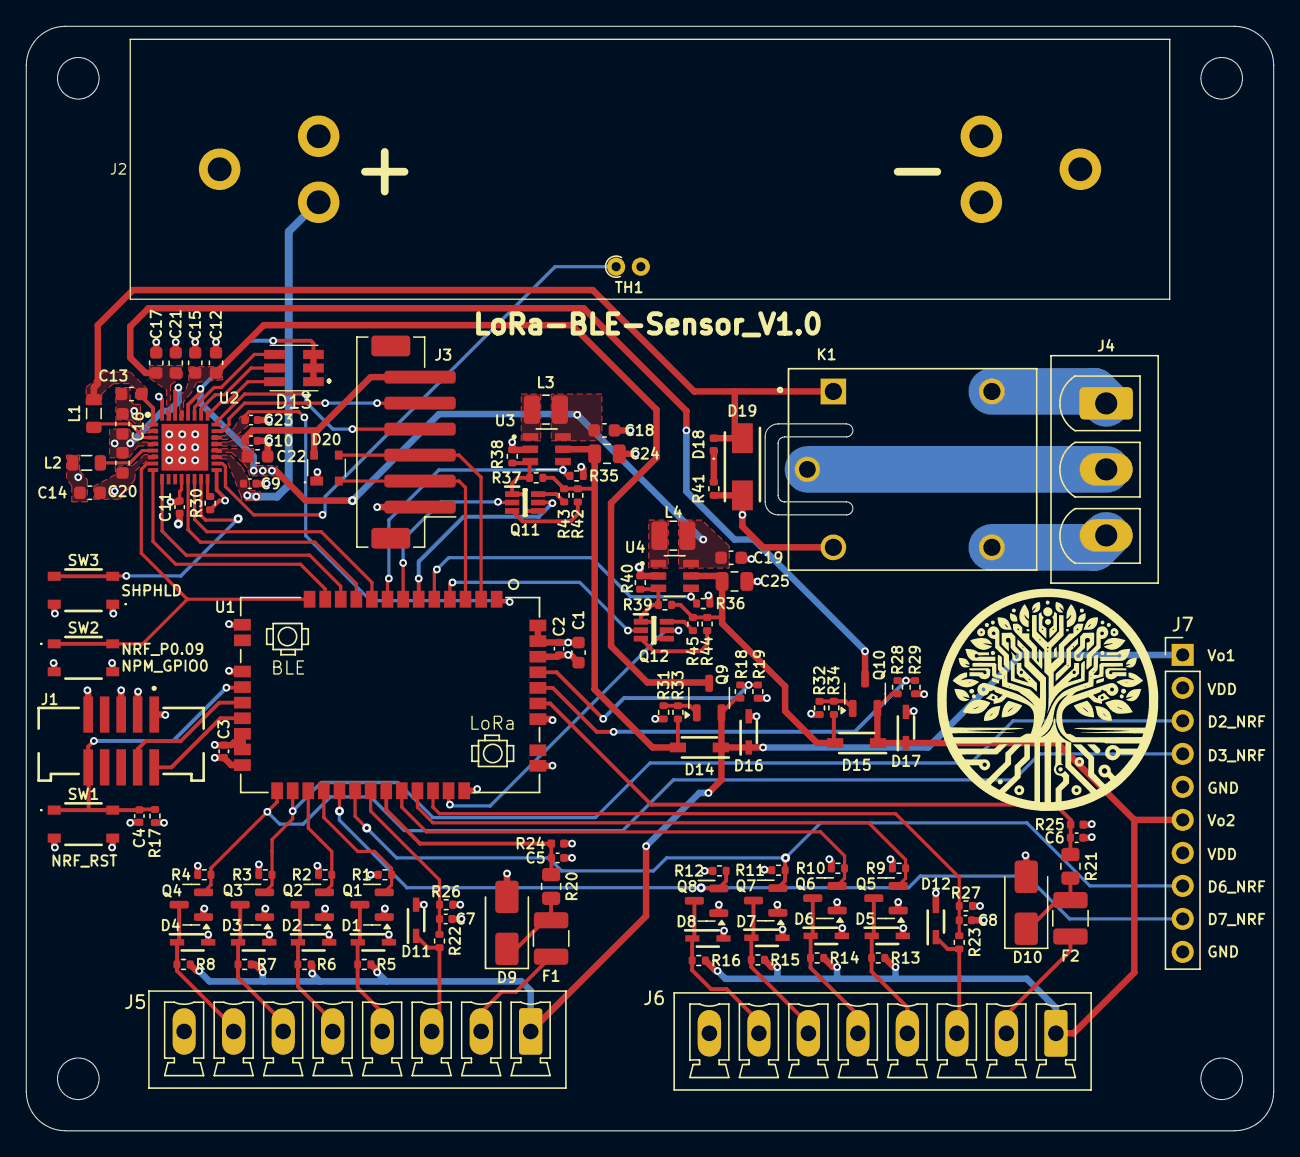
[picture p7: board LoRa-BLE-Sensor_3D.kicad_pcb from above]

Board: 4 copper layers, 96.0 x 85.0 mm, 124 parts (0 on the bottom side), 81 nets.

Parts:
C1, C12, C13, C14, C15, C16, C17, C18, C19, C20, C21, C22: 10u; C_0603_1608Metric
C2, C3, C4, C11: 100n; C_0402_1005Metric
C5, C6, C7, C8: 470p; C_0402_1005Metric
C9: 2u2; C_0402_1005Metric
C10, C23: 1u; C_0402_1005Metric
C24, C25: 10u; C_0805_2012Metric
D1, D2, D3, D4, D5, D6, D7, D8, D11, D12, D16, D17: UDD32C24L01; SOD2612X120N
D9, D10: SMAJ10CA; D_SMA
D13: ASMB-TTF0-0A20B; ASMBTTF00A20B
D14, D15: BAT54W-HG3-08; SOD3716X135N
D18: GREEN; LED_0402_1005Metric
D19: M7; DIOM5327X240N
D20: PRTR5V0U2X,215; PRTR5V0U2X
F1, F2: MF-USMF005-2; Fuse_1210_3225Metric
J1: SHF-105-01-X-D-SM; SAMTEC_SHF-105-01-X-D-SM
J2: Battery_Cell; 18650_CLIP_PROTECTED
J3: Conn_01x06_Socket; JST_6PIN_PH_VERTICAL_SMD
J4: Screw_Terminal_01x03; PhoenixContact_MCV_1x03_P5.08mm_Vertical
J5, J6: Screw_Terminal_01x08; PhoenixContact_MCV_1,5_8-G-3.81_1x08_P3.81mm_Vertical
J7: Conn_01x10_Pin; PinHeader_1x10_P2.54mm_Vertical
K1: SRD-05VDC-SL-C; RELAY_SRD-05VDC-SL-C
L1, L2: 2u2; L_0805_2012Metric
L3, L4: 10U; L_1008_2520Metric
Q1, Q2, Q3, Q4, Q5, Q6, Q7, Q8: DMN67D7L; SOT-23
Q9, Q10: SQ2389ES; SOT-23-3
Q11, Q12: DMN62D0UDW-7; SOT65P222X110-6N
R1, R2, R3, R4, R5, R6, R7, R8, R9, R10, R11, R12, R13, R14, R15, R16, R17, R35, R36, R41: 10K; R_0402_1005Metric
R18, R22, R23, R28: 100K; R_0402_1005Metric
R19, R26, R27, R29: 13K; R_0402_1005Metric
R20, R21: 180R; R_0805_2012Metric
R24, R25: 50R; L_0402_1005Metric
R30, R31, R32, R33, R34: 500K; R_0402_1005Metric
R37, R39: 2M1; R_0402_1005Metric
R38, R40: 71K5; R_0402_1005Metric
R42, R44: 1M96; R_0402_1005Metric
R43, R45: 604K; R_0402_1005Metric
SW1, SW2, SW3: SW_Push; PTS815SJM250SMTRLFS_2Pin
TH1: 10K; R_Axial_DIN0204_L3.6mm_D1.6mm_P1.90mm_Vertical
U1: RAK4630
U2: NPM1300-QEAA-R; QFN50P500X500X90-33N
U3, U4: TLV61046ADBVR; SOT95P280X145-6N

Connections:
BOOST1_EN: R35.1, U1.8 (P0.17), U3.4 (EN)
BOOST1_FB: Q11.1 (S2), Q11.4 (S1), R37.2, R38.1, U3.3 (FB)
BOOST1_FB_CTRL1: Q11.5 (G1), U1.6 (P0.15)
BOOST1_FB_CTRL2: Q11.2 (G2), U1.7 (P0.16)
BOOST2_EN: R36.1, U1.5 (P0.14), U4.4 (EN)
BOOST2_FB: Q12.1 (S2), Q12.4 (S1), R39.2, R40.1, U4.3 (FB)
BOOST2_FB_CTRL1: Q12.5 (G1), U1.34 (P0.26)
BOOST2_FB_CTRL2: Q12.2 (G2), U1.4 (P0.13)
BUT1: SW2.1, U1.13 (P0.09), U2.7 (GPIO0)
CC1: J3.5, U2.23 (CC1)
CC2: J3.4, U2.24 (CC2)
D0_IN: D1.1, J5.4, Q1.3 (D), R5.2
D0_NRF: Q1.2 (S), R1.2, U1.26 (P1.02)
D1_IN: D2.1, J5.5, Q2.3 (D), R6.2
D1_NRF: Q2.2 (S), R2.2, U1.25 (P1.01)
D2_IN: D3.1, J5.6, Q3.3 (D), R7.2
D2_NRF: J7.3, Q3.2 (S), R3.2, U1.24 (P0.25)
D3_IN: D4.1, J5.7, Q4.3 (D), R8.2
D3_NRF: J7.4, Q4.2 (S), R4.2, U1.23 (P0.24)
D4_IN: D5.1, J6.4, Q5.3 (D), R13.2
D4_NRF: Q5.2 (S), R9.2, U1.32 (P0.29)
D5_IN: D6.1, J6.5, Q6.3 (D), R14.2
D5_NRF: Q6.2 (S), R10.2, U1.31 (P0.28)
D6_IN: D7.1, J6.6, Q7.3 (D), R15.2
D6_NRF: J7.8, Q7.2 (S), R11.2, U1.28 (P1.04)
D7_IN: D8.1, J6.7, Q8.3 (D), R16.2
D7_NRF: J7.9, Q8.2 (S), R12.2, U1.27 (P1.03)
GND: C1.2, C2.2, C3.2, C4.2, C5.2, C6.2, C7.2, C8.2, C9.2, C10.2, C11.2, C12.2, C13.2, C14.2, C15.2, C16.2, C17.2, C18.2, C19.2, C20.2, C21.2, C22.2, C23.2, C24.2, C25.2, D1.2, D2.2, D3.2, D4.2, D5.2, D6.2, D7.2, D8.2, D9.2 (A2), D10.2 (A2), D11.2, D12.2, D16.2, D17.2, D19.2 (A), D20.1 (GND), J1.03 (GND), J1.05 (GND), J1.09 (GNDDetect), J2.2 (-), J3.1, J5.8, J6.8, J7.5, J7.10, K1.A2, R19.2, R24.2, R25.2, R26.2, R27.2, R29.2, R30.2, R31.1, R32.1, R35.2, R36.2, R38.2, R40.2, R41.1, SW1.2, SW2.2, SW3.1, TH1.2, U1.14 (GND), U1.16 (GND), U1.22 (GND), U1.35 (GND), U1.36 (GND), U1.38 (GND), U1.42 (GND), U2.2 (PVSS1), U2.6 (PVSS2), U2.17 (VSET1), U2.33 (PAD), U3.2 (GND), U4.2 (GND)
I0_IN: F1.1, J5.2
I0_NRF: C5.1, R20.2, R24.1, U1.30 (P0.02)
I1_IN: F2.1, J6.2
I1_NRF: C6.1, R21.2, R25.1, U1.39 (P0.31)
LDO1_OUT: C12.1, C15.1, Q9.3 (D), U2.29 (LSOUT1/VOUTLDO1)
LDO2_OUT: C17.1, C21.1, Q10.3 (D), U2.31 (LSOUT2/VOUTLDO2)
NPM_IO1: U1.12 (P0.10), U2.8 (GPIO1)
NPM_IO2: U1.11 (P0.21), U2.9 (GPIO2)
NPM_SCL: U1.9 (P0.19), U2.14 (SCL)
NPM_SDA: U1.10 (P0.20), U2.13 (SDA)
unnamed: D9.1 (A1), F1.2, R20.1
unnamed: D10.1 (A1), F2.2, R21.1
unnamed: D13.6 (KB), U2.27 (LED2)
unnamed: D13.4 (KG), U2.26 (LED1)
unnamed: D13.2 (KR), U2.25 (LED0)
unnamed: D18.1 (K), R41.2
unnamed: J4.1, K1.NC
unnamed: J4.2, K1.COM
unnamed: J4.3, K1.NO
unnamed: Q9.1 (G), R31.2, R33.1
unnamed: Q10.1 (G), R32.2, R34.1
unnamed: Q11.3 (D1), R42.2
unnamed: Q11.6 (D2), R43.2
unnamed: Q12.3 (D1), R44.2
unnamed: Q12.6 (D2), R45.2
unnamed: TH1.1, U2.18 (NTC)
unnamed: SW3.2, U2.15 (SHPHLD)
unnamed: L1.2, U2.3 (SW1)
unnamed: L2.2, U2.5 (SW2)
unnamed: R30.1, U2.16 (VSET2)
unnamed: L3.2, U3.1 (SW)
unnamed: L4.2, U4.1 (SW)
RESET: C4.1, J1.10 (nRESET), R17.2, SW1.1, U1.17 (NRF_RESET)
SWCLK: J1.04 (SWDCLK/TCK), U1.18 (SWDCLK)
SWDIO: J1.02 (SWDIO/TMS), U1.19 (SWDIO)
USB_D+: D20.2 (I/O1), J3.2, U1.3 (USB+)
USB_D-: D20.3 (I/O2), J3.3, U1.2 (USB-)
V0_IN: D11.1, J5.3, R22.1
V0_NRF: C7.1, R22.2, R26.1, U1.29 (P0.03)
V1_IN: D12.1, J6.3, R23.1
V1_NRF: C8.1, R23.2, R27.1, U1.33 (P0.30)
VBAT: C9.1, J2.1 (+), U2.19 (VBAT)
VBOOST1: C24.1, D14.2 (A), R33.2, R37.1, R42.1, R43.1, U3.5 (VOUT)
VBOOST2: C25.1, D15.2 (A), R34.2, R39.1, R44.1, R45.1, U4.5 (VOUT)
VBUS: C10.1, D20.4 (VCC), J3.6, U2.21 (VBUS)
VBUS_NRF: C23.1, U1.1 (VBUS), U2.22 (VBUSOUT)
VDD: C1.1, C2.1, C3.1, C11.1, C14.1, J1.01 (VTref), J7.2, J7.7, L2.1, Q1.1 (G), Q2.1 (G), Q3.1 (G), Q4.1 (G), Q5.1 (G), Q6.1 (G), Q7.1 (G), Q8.1 (G), R1.1, R2.1, R3.1, R4.1, R9.1, R10.1, R11.1, R12.1, R17.1, U1.20 (VBAT_SX), U1.21 (VBAT_IO_SX), U1.43 (VDD_NRF), U1.44 (VBAT_NRF), U2.12 (VDDIO), U2.32 (VOUT2)
VSYS: C16.1, C18.1, C19.1, C20.1, C22.1, D13.1 (AR), D13.3 (AG), D13.5 (AB), L3.1, L4.1, U2.4 (PVDD), U2.20 (VSYS), U2.28 (LSIN1/VINLDO1), U2.30 (LSIN2/VINLDO2), U3.6 (VIN), U4.6 (VIN)
V_RELAY: C13.1, D18.2 (A), D19.1 (K), K1.A1, L1.1, U2.1 (VOUT1)
V_SENSOR1: D14.1 (K), D16.1, J5.1, J7.1, Q9.2 (S), R5.1, R6.1, R7.1, R8.1, R18.1
V_SENSOR1_READ: R18.2, R19.1, U1.41 (P0.04)
V_SENSOR2: D15.1 (K), D17.1, J6.1, J7.6, Q10.2 (S), R13.1, R14.1, R15.1, R16.1, R28.1
V_SENSOR2_READ: R28.2, R29.1, U1.40 (P0.05)

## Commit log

2025-03-06 Schematic + JPEG
    [LoRa-BLE-Sensor.kicad_sch, LoRa-BLE-Sensor_3D.kicad_pcb]
2025-03-06 File Naming
    [LoRa-BLE-Sensor.kicad_pcb]
2025-03-06 updated schematic
    [LoRa-BLE-Sensor-B_Cu.gbr, LoRa-BLE-Sensor-B_Mask.gbr, LoRa-BLE-Sensor-B_Paste.gbr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]
2025-03-12 placement file
    [LoRa-BLE-Sensor-all-pos.csv]
2025-03-12 rearranged files
    [LoRa-BLE-Sensor-B_Cu.gbr, LoRa-BLE-Sensor-B_Mask.gbr, LoRa-BLE-Sensor-B_Paste.gbr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]
2025-05-21 beginning V1.1 deisgn
    [LoRa-BLE-Sensor.kicad_sch]
2025-05-22 renaming pin labels
    [LoRa-BLE-Sensor.kicad_pcb, LoRa-BLE-Sensor.kicad_sch]
2025-05-22 removed power switch voltage dividers
    [LoRa-BLE-Sensor.kicad_sch]
2025-05-22 added sensor 3
    [LoRa-BLE-Sensor.kicad_pcb, LoRa-BLE-Sensor.kicad_sch]
2025-05-23 sensor3 schematic almost done
    [LoRa-BLE-Sensor.kicad_pcb, LoRa-BLE-Sensor.kicad_sch]
2025-05-23 Beginning routing V1.1
    [LoRa-BLE-Sensor.kicad_pcb, LoRa-BLE-Sensor.kicad_sch]
2025-05-23 labels fixed
    [LoRa-BLE-Sensor.kicad_pcb]
2025-05-23 signal routing
    [LoRa-BLE-Sensor.kicad_pcb, LoRa-BLE-Sensor.kicad_sch]
2025-05-23 NFC antenna route + connector
    [LoRa-BLE-Sensor.kicad_pcb, LoRa-BLE-Sensor.kicad_sch]
2025-05-23 mounting holes + routing
    [LoRa-BLE-Sensor.kicad_pcb, LoRa-BLE-Sensor.kicad_sch]
2025-05-24 all tracks routed and DRC passed
    [LoRa-BLE-Sensor.kicad_pcb, LoRa-BLE-Sensor.kicad_sch]
2025-05-24 finished renaming and routing
    [LoRa-BLE-Sensor.kicad_pcb, LoRa-BLE-Sensor.kicad_sch]
2025-05-27 replaced battery connectors
    [LoRa-BLE-Sensor.kicad_pcb, LoRa-BLE-Sensor.kicad_sch]
2025-05-27 switching branches
2025-05-27 rearranged board down to 60mm
    [LoRa-BLE-Sensor.kicad_pcb, LoRa-BLE-Sensor.kicad_sch]
2025-05-27 external battery design finished
    [LoRa-BLE-Sensor.kicad_pcb, LoRa-BLE-Sensor.kicad_sch]
2025-05-27 schematic update
    [LoRa-BLE-Sensor.kicad_sch]
2025-05-27 user drawings
    [LoRa-BLE-Sensor.kicad_pcb]
2025-05-27 switch branches
    [LoRa-BLE-Sensor.kicad_sch]
2025-05-27 external battery merged to main
2025-05-27 shortened width by 5mm
    [LoRa-BLE-Sensor.kicad_pcb]
2025-05-29 added docs and manufacturing V1.1
    [LoRa-BLE-Sensor-B_Cu.gbr, LoRa-BLE-Sensor-B_Mask.gbr, LoRa-BLE-Sensor-B_Paste.gbr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]
2025-05-29 added logo to front
    [LoRa-BLE-Sensor.kicad_pcb]
2025-05-29 added pdf to schematic
2025-05-29 manufacturing update
    [LoRa-BLE-Sensor_V1.1.csv]
2025-05-29 Changed BOM name
    [LoRa-BLE-Sensor_V1.1_BOM.csv]
